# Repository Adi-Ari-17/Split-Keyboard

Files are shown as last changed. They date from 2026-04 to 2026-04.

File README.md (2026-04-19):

# Split-Keyboard

This is my first time building a full keyboard, although I have built a macropad before. It is a split keyboard, and I am building it to test out connection between two microcontrollers.

## PCB

This is my PCB for the keyboard, in this photo it is disconnected so I can make the case around it in onshpae.

Screenshot 2026-04-05 at 7 08 44 PM

I know it looks a little messy but I plan on the case being not a thing layer just covering it and acctually giving it a shape.

This is the schmatic for my PCB I used this as a parent page so I can just copy the two halves of the keyboard.
Screenshot 2026-04-05 at 7 10 56 PM

This is one of the pages, the left side, but both are identical
Screenshot 2026-04-05 at 7 11 12 PM

This the 3d view (it is still not connected)

Screenshot 2026-04-05 at 7 14 44 PM

## CAD

I worked on my CAD two seperate times the first time I had the PCB connected and I couldn't figure out a good way to split it so I made a base model

After I splitted it in Kicad I made my case. I paticularly like this design it looks minamilistic, but it also looks kinda unique. 

 Screenshot 2026-04-09 at 4 59 49 PM

 I used a little help from my friend to make this cause I'm not the best at CAD. :) 

 I also had to make to seperate models cause each of my keyboard sides are different. (heh)

 ## Code

 I just used the Zmk method and watched some out of date videos for this one
 I used a bit of Claude for debugging and finding out what I should plug in where.
 I also used AI for the keymaps since it is a lot of repeating work

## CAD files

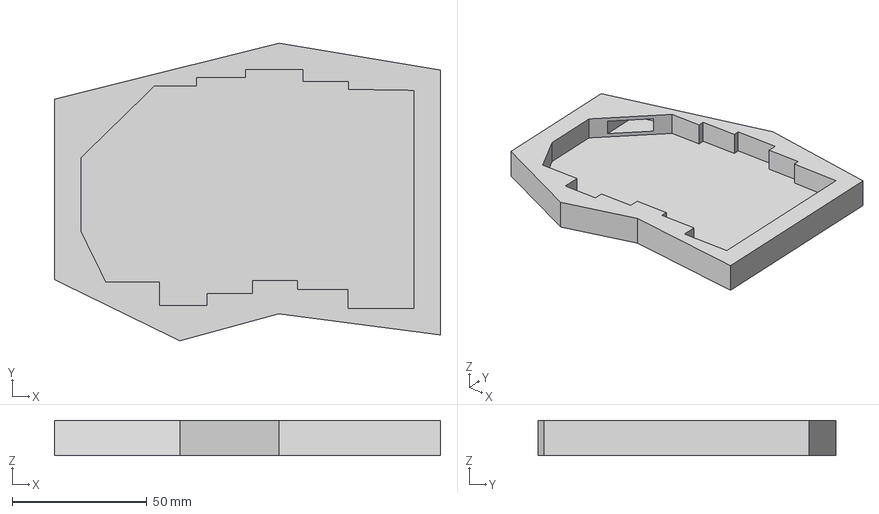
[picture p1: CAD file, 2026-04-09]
CAD/Left Side/BottomLeftSplitKeyboard.step
143.0 x 110.3 x 13.0 mm

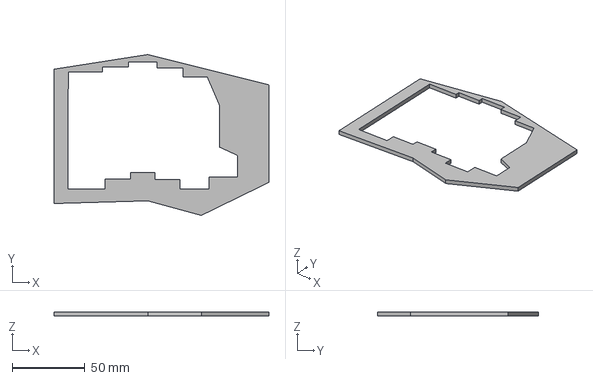
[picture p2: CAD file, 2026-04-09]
CAD/Right Side/TopRightSplitKeyboard.step
147.4 x 110.3 x 3.00 mm

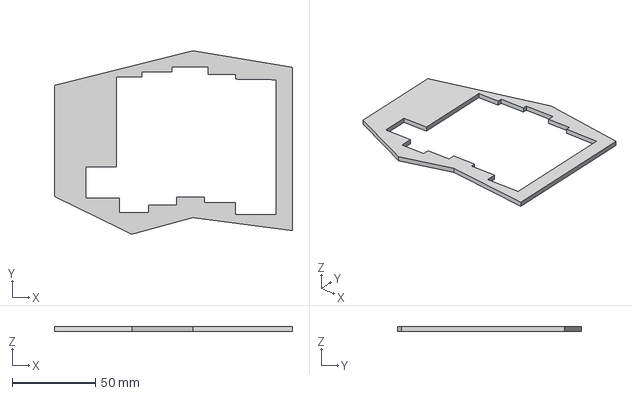
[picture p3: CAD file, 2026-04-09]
CAD/Left Side/TopLeftSplitKeyboard.step
143.0 x 110.3 x 3.00 mm

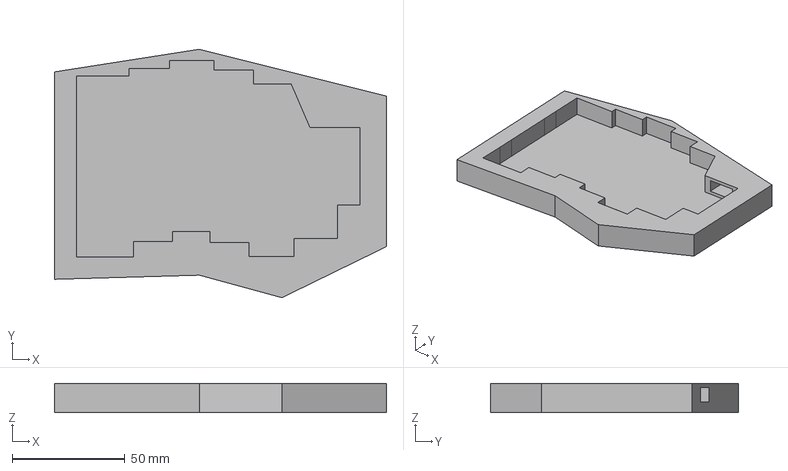
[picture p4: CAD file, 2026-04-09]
CAD/Right Side/BottomRightSplitKeyboard.step
147.4 x 110.3 x 13.0 mm

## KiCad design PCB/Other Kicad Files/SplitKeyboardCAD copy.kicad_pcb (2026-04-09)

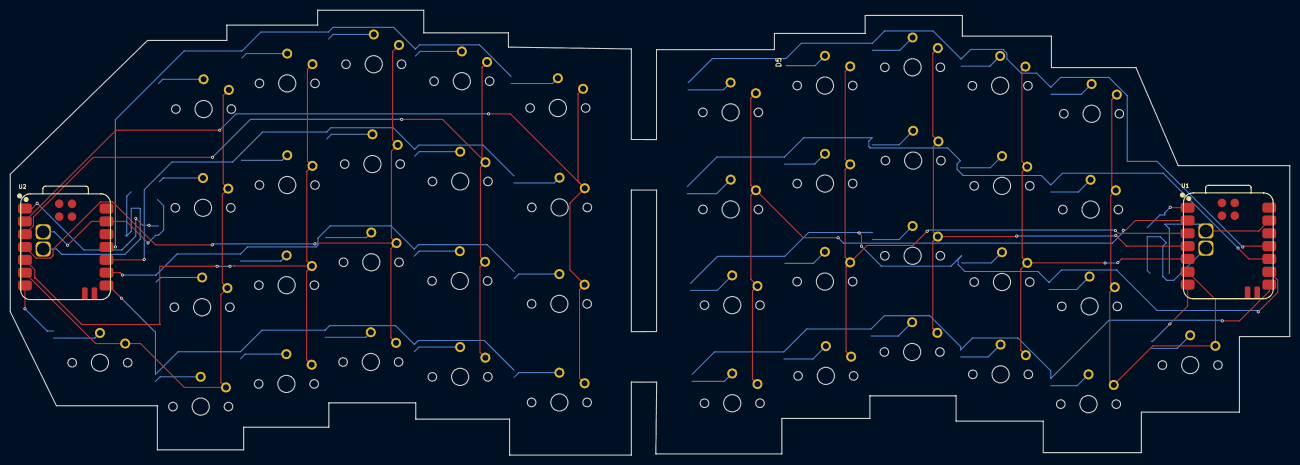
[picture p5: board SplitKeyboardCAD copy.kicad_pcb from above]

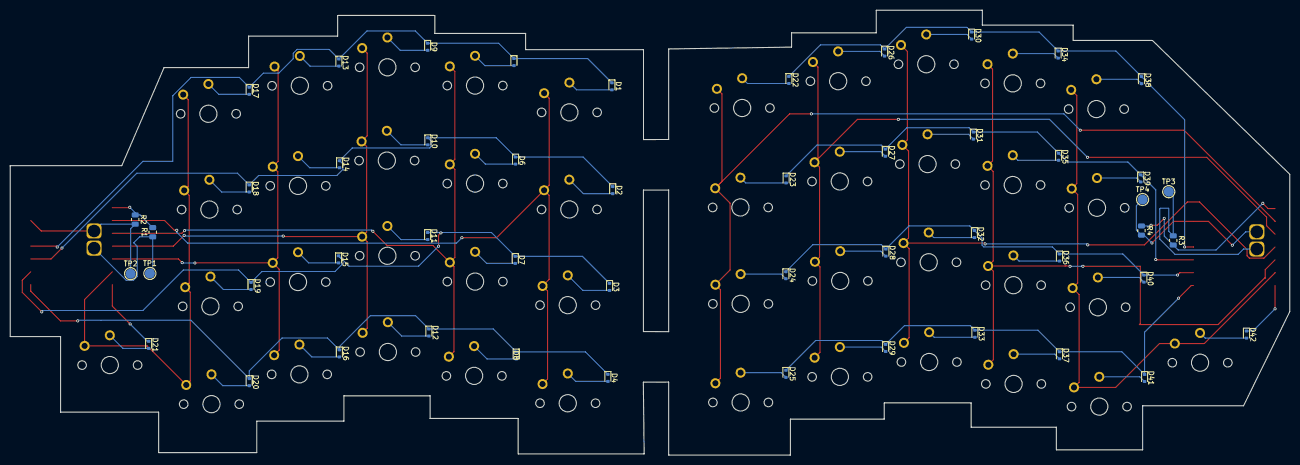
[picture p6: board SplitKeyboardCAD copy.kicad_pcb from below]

Board: 2 copper layers, 253.5 x 88.1 mm, 94 parts (50 on the bottom side), 55 nets.

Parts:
D1, D2, D3, D4, D5, D6, D7, D8, D9, D10, D11, D12, D13, D14, D15, D16, D17, D18, D19, D20, D21, D22, D23, D24, D25, D26, D27, D28, D29, D30, D31, D32, D33, D34, D35, D36, D37, D38, D39, D40, D41, D42: 1N4148WT; D_SOD-523
R1, R3: 806k; R_0805_2012Metric
R2, R4: 2M; R_0805_2012Metric
SW1, SW2, SW3, SW4, SW5, SW6, SW7, SW8, SW9, SW10, SW11, SW12, SW13, SW14, SW15, SW16, SW17, SW18, SW19, SW20, SW21, SW22, SW23, SW24, SW25, SW26, SW27, SW28, SW29, SW30, SW31, SW32, SW33, SW34, SW35, SW36, SW37, SW38, SW39, SW40, SW41, SW42: SW_Push; SW_choc_v1_1.75u
TP1, TP3: BAT; TestPoint_Pad_D2.0mm
TP2, TP4: GND; TestPoint_Pad_D2.0mm
U1, U2: XIAO-nRF52840-SMD; modified-XIAO-nRF52840-SMD

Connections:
BT_PIN: R1.2, R2.1, R3.2, R4.1, U1.1 (P0.02_A0_D0), U2.1 (P0.02_A0_D0)
Column0: SW1.1, SW2.1, SW3.1, SW4.1, SW22.1, SW23.1, SW24.1, SW25.1, U1.2 (P0.03_A1_D1), U2.2 (P0.03_A1_D1)
Column1: SW5.1, SW6.1, SW7.1, SW8.1, SW26.1, SW27.1, SW28.1, SW29.1, U1.3 (P0.28_A2_D2), U2.3 (P0.28_A2_D2)
Column2: SW9.1, SW10.1, SW11.1, SW12.1, SW30.1, SW31.1, SW32.1, SW33.1, U1.4 (P0.29_A3_D3), U2.4 (P0.29_A3_D3)
Column3: SW13.1, SW14.1, SW15.1, SW16.1, SW34.1, SW35.1, SW36.1, SW37.1, U1.5 (P0.04_A4_D4_SDA), U2.5 (P0.04_A4_D4_SDA)
Column4: SW17.1, SW18.1, SW19.1, SW20.1, SW21.1, SW38.1, SW39.1, SW40.1, SW41.1, SW42.1, U1.6 (P0.05_A5_D5_SCL), U2.6 (P0.05_A5_D5_SCL)
GND: R2.2, R4.2, TP2.1, TP4.1, U1.13 (GND), U1.16 (GND), U2.13 (GND), U2.16 (GND)
unnamed: D1.2 (A), SW1.2
unnamed: D2.2 (A), SW2.2
unnamed: D3.2 (A), SW3.2
unnamed: D4.2 (A), SW4.2
unnamed: D5.2 (A), SW5.2
unnamed: D6.2 (A), SW6.2
unnamed: D7.2 (A), SW7.2
unnamed: D8.2 (A), SW8.2
unnamed: D9.2 (A), SW9.2
unnamed: D10.2 (A), SW10.2
unnamed: D11.2 (A), SW11.2
unnamed: D12.2 (A), SW12.2
unnamed: D13.2 (A), SW13.2
unnamed: D14.2 (A), SW14.2
unnamed: D15.2 (A), SW15.2
unnamed: D16.2 (A), SW16.2
unnamed: D17.2 (A), SW17.2
unnamed: D18.2 (A), SW18.2
unnamed: D19.2 (A), SW19.2
unnamed: D20.2 (A), SW20.2
unnamed: D21.2 (A), SW21.2
unnamed: D22.2 (A), SW22.2
unnamed: D23.2 (A), SW23.2
unnamed: D24.2 (A), SW24.2
unnamed: D25.2 (A), SW25.2
unnamed: D26.2 (A), SW26.2
unnamed: D27.2 (A), SW27.2
unnamed: D28.2 (A), SW28.2
unnamed: D29.2 (A), SW29.2
unnamed: D30.2 (A), SW30.2
unnamed: D31.2 (A), SW31.2
unnamed: D32.2 (A), SW32.2
unnamed: D33.2 (A), SW33.2
unnamed: D34.2 (A), SW34.2
unnamed: D35.2 (A), SW35.2
unnamed: D36.2 (A), SW36.2
unnamed: D37.2 (A), SW37.2
unnamed: D38.2 (A), SW38.2
unnamed: D39.2 (A), SW39.2
unnamed: D40.2 (A), SW40.2
unnamed: D41.2 (A), SW41.2
unnamed: D42.2 (A), SW42.2
Row0: D1.1 (K), D5.1 (K), D9.1 (K), D13.1 (K), D17.1 (K), D22.1 (K), D26.1 (K), D30.1 (K), D34.1 (K), D38.1 (K), U1.11 (P1.15_D10_MOSI), U2.11 (P1.15_D10_MOSI)
Row1: D2.1 (K), D6.1 (K), D10.1 (K), D14.1 (K), D18.1 (K), D23.1 (K), D27.1 (K), D31.1 (K), D35.1 (K), D39.1 (K), U1.10 (P1.14_D9_MISO), U2.10 (P1.14_D9_MISO)
Row2: D3.1 (K), D7.1 (K), D11.1 (K), D15.1 (K), D19.1 (K), D24.1 (K), D28.1 (K), D32.1 (K), D36.1 (K), D40.1 (K), U1.9 (P1.13_D8_SCK), U2.9 (P1.13_D8_SCK)
Row3: D4.1 (K), D8.1 (K), D12.1 (K), D16.1 (K), D20.1 (K), D25.1 (K), D29.1 (K), D33.1 (K), D37.1 (K), D41.1 (K), U1.8 (P1.12_D7_RX), U2.8 (P1.12_D7_RX)
Row4: D21.1 (K), D42.1 (K), U1.7 (P1.11_D6_TX), U2.7 (P1.11_D6_TX)
VBAT: R1.1, R3.1, TP1.1, TP3.1, U1.15 (BAT), U2.15 (BAT)

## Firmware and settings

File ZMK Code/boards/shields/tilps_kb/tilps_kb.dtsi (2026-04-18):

/*
 * Tilps KB — shared shield definition
 *
 * Hardware:  XIAO nRF52840 (both halves, same PCB mirrored)
 * Matrix:    5 rows × 5 cols per half (21 keys per half, 42 total)
 *            Rows   : P1.15 P1.14 P1.13 P1.12 P1.11
 *            Cols   : P0.03 P0.28 P0.29 P0.04 P0.05
 *            Diodes : column-to-row (col2row)
 *
 * Key layout (42 keys):
 *  Row 0 :  Q    W    E    R    T  |  Y    U    I    O    P
 *  Row 1 :  A    S    D    F    G  |  H    J    K    L    ;
 *  Row 2 :  Z    X    C    V    B  |  N    M    ,    .    /
 *  Row 3 :  LSft Tab  LCt  LAlt GUI|  Spc  Ret  BSp  Del  RAlt
 *  Thumb :                   MO(1) |  MO(2)
 */

#include <dt-bindings/zmk/matrix_transform.h>

/ {
    chosen {
        zmk,kscan = &kscan0;
        zmk,matrix_transform = &default_transform;
    };

    /*
     * Combined 5-row × 10-column transform.
     * Left  half → columns 0-4  (col 0 = outermost, col 4 = innermost)
     * Right half → columns 5-9  (col 5 = innermost, col 9 = outermost)
     * Thumb keys: RC(4,4) = left thumb, RC(4,5) = right thumb
     */
    default_transform: keymap_transform_0 {
        compatible = "zmk,matrix-transform";
        columns = <10>;
        rows = <5>;
        map = <
RC(0,0) RC(0,1) RC(0,2) RC(0,3) RC(0,4)   RC(0,5) RC(0,6) RC(0,7) RC(0,8) RC(0,9)
RC(1,0) RC(1,1) RC(1,2) RC(1,3) RC(1,4)   RC(1,5) RC(1,6) RC(1,7) RC(1,8) RC(1,9)
RC(2,0) RC(2,1) RC(2,2) RC(2,3) RC(2,4)   RC(2,5) RC(2,6) RC(2,7) RC(2,8) RC(2,9)
RC(3,0) RC(3,1) RC(3,2) RC(3,3) RC(3,4)   RC(3,5) RC(3,6) RC(3,7) RC(3,8) RC(3,9)
                                RC(4,4)    RC(4,5)
        >;
    };

    /*
     * Keyboard scan — rows defined here (same on both halves).
     * Each overlay adds the col-gpios appropriate for that half.
     * Row GPIOs: P1.15 P1.14 P1.13 P1.12 P1.11 (diode col2row → rows = inputs)
     */
    kscan0: kscan {
        compatible = "zmk,kscan-gpio-matrix";
        wakeup-source;
        diode-direction = "col2row";

        row-gpios
            = <&gpio1 15 (GPIO_ACTIVE_HIGH | GPIO_PULL_DOWN)>   /* Row0 – P1.15 */
            , <&gpio1 14 (GPIO_ACTIVE_HIGH | GPIO_PULL_DOWN)>   /* Row1 – P1.14 */
            , <&gpio1 13 (GPIO_ACTIVE_HIGH | GPIO_PULL_DOWN)>   /* Row2 – P1.13 */
            , <&gpio1 12 (GPIO_ACTIVE_HIGH | GPIO_PULL_DOWN)>   /* Row3 – P1.12 */
            , <&gpio1 11 (GPIO_ACTIVE_HIGH | GPIO_PULL_DOWN)>   /* Row4 – P1.11 (thumb) */
            ;
    };

    /*
     * Battery voltage divider
     *   VBAT → R1 (805 kΩ) → sense node → R2 (2 MΩ) → GND
     *   sense pin = P0.02 / AIN0 / ADC channel 0
     */
    vbatt: vbatt {
        compatible = "zmk,battery-voltage-divider";
        io-channels = <&adc 0>;
        output-ohms = <2000000>;
        full-ohms = <2805000>;
    };
};

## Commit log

2026-04-09 Add PCB files
    [SplitKeyboardCAD copy.kicad_pcb, SplitKeyboardCAD copy.kicad_sch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]
2026-04-09 Add exported PCB and CAD files
    [BottomLeftSplitKeyboard.step, BottomRightSplitKeyboard.step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]
